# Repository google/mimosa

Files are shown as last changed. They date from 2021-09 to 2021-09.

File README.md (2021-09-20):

# MIMOSA

MIMOSA - **M**ultiple **I**nput **M**ultiple **O**utput **S**witches. The mission of the project is to capture user's intent via as many physiological triggers (press of button, blink of an eye, flick of a cheek, shake of a toe) as possible, and provide an easy interface to transduce the intent into digital actions.

At this time MIMOSA is focused on enabling students, makers, and DIY community to quickly prototype accessible and inclusive input devices. In the future the list of complete functional and tested devices (together with bills of materials and assembly+programming instructions) will be expanding. Please see the section "Reference Devices" below for some of the devices currently prototyped.

# System Features
1. **Sensitive and adaptive** - focus on the users abilities, that could be changing over time.
2. **Maker-friendly** - the system is comprised of components that are easy to get (via Sparkfun, Adafruit, Digikey), and easy to program (support for Arduino, CircuitPython).
3. **Extandable** - multi-modal sensing modules can be daisy chained together to enable multi-trigger applications (gaming, chorded typing, advanced device control, etc.)
4. **Low-cost**. The system is breathing accessibility not only with it's functions, but also with the price point.
5. **Well-documented reference designs** - mouse control, fast-typing and accessible keyboard, gaming, Android device control, ChromeOS device control.

While MIMOSA is not an officially Google supported project, it is a great start for engineers, makers, students, hobbyists into versatile and accessible input devices.

# Example Development and Deployment Process
1. Define sensing modalities and strategies for triggering. 
2. Put together a system with MIMOSA modules to provide means for sensing and user feedback. Two tips:
  a. Often it is a good idea to start with a block diagram and a high level design document.
  b. Iterate quickly. Engage with the users early.
3. Test the system with the user and adjust sensitivity settings, modules placement, mechanical arrangements, etc.

# Custom Modules - Design Blueprints Available Throught This Repository
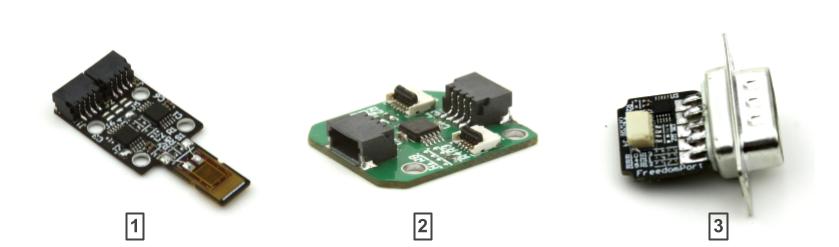
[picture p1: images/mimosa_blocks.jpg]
blocks

1. **High dynamic range force sensor**. This board can be used to monitor force application along 1 axis with an impressive sensitivity (well below 1g), and good dynamic range such that a stronger force can still be registered without saturation.
2. **Joystick interface**. The goal of the board is to provide a solderless interface board compatible with the tiny joysticks available on the market. Tested with [1](https://www.adafruit.com/product/3103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), [2](https://www.amazon.com/gp/product/B08397JQZG).
3. **D-sub 9-pin joystick interface** inspired by FreedomWing. Allows the connection of a widely used DB9 joysticks into the Stemma QT aka QWIIC infrastructure.

# Off-the-shelf Module Ideas
As MIMOSA is based on a widely adopted solderless communication and power distribution system (Adafruit Stemma QT, or Sparkfun QWIIC), there are many modules developed for all sort of applications that can be used together with MIMOSA modules. 

Examples of such modules:
- IMU modules, magnetometers, accelerometeres, gyroscopes.
- Proximity sensors
- Interface boards

# Reference Devices
Based on the modules developped there are a few reference implmentations of ready to go devices for end user applications. All devices are ready to go out of the box. All devices also come Arduino and/or CircuitPython compatible, so they are very easy to modify for different applications, different abilities, and expanded to comprise more sophisticated systems.

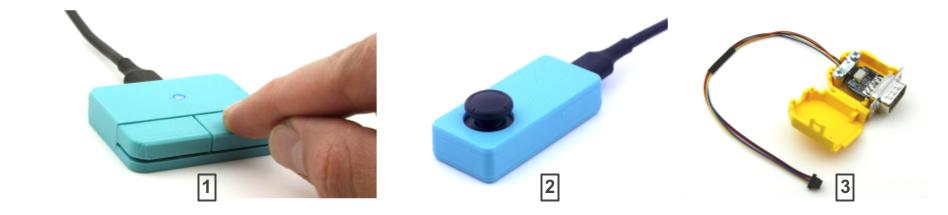
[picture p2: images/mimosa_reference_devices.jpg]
devices


Following devices are provided as a reference: 
1. Dual force buttons with USB-C interface that supports standards HID mouse/keyboard protocol.
2. Tiny joystick (tinyjoy). Just a standalone small joystick device with USB-C interface.
  a. HID joystick implementation.
  b. HID mouse implmentation.

More complex devices available through separate repositories:

4. Palmouse - magnetometer-based airmouse (inclination -> mouse speed) with an additional joystick, two MIMOSA force buttons, and USB interface.
5. Chorda - simiar form factor as Palmouse, this device is built for both hands, with two additional buttons on each hand. The key idea is that it cab be used as a mouse and as a chorded keyboard!

# Navigating the Repository
- The directories with names starting with "pcba_" are the source files of the custom modules described above (schematics + board layour + bom + fabrication files). They also include accompanying arduino libraries and examples where applicable. 
- The directories with the names starting with "device" contain the source files and code examples needed to put together complete devices. This usually includes a mechanical enclosure, photos, and documentation.

# Source Files
1. Schematic diagram + board layout (Altium).
2. Enclosure (STLs, STEP file exported from Autocad Fusion 360).
3. Firmware libraries and sketches compatible with Arduino IDE are included.

# License
This project is licensed under the Apache v2.0 License - see the [LICENSE.md](LICENSE.md) file for details

# Contributing
Thank you for your interest - please review CONTRIBUTING.md!

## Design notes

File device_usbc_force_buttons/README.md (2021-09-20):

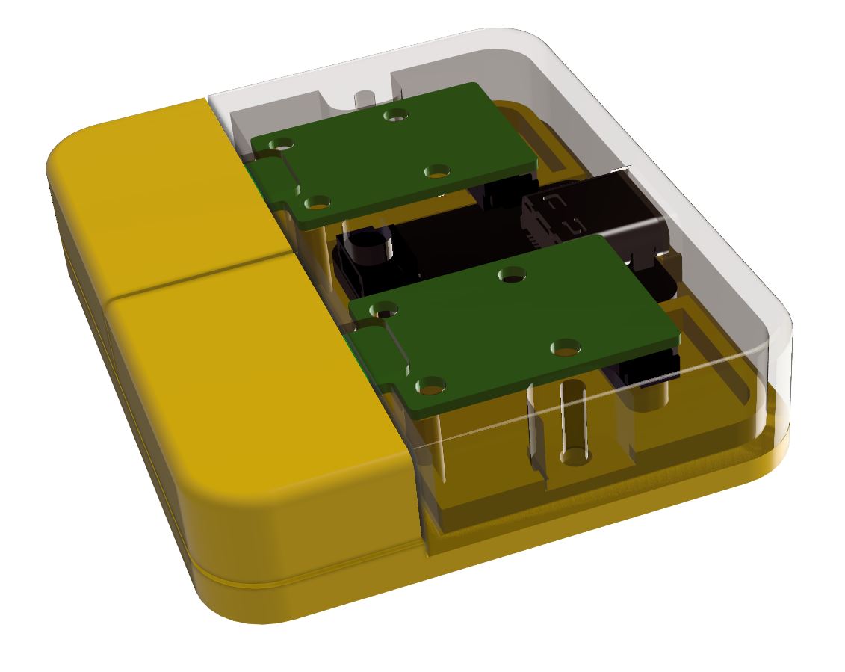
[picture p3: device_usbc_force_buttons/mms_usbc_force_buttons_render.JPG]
USB-C Force Buttons Render


# Getting Started

When the USB-C cord is plugged in the device should show up as an HID keyboard (assuming default setting). Try pressing the buttons and see if you can get the two letter from the two buttons to show up in the Notepad window.

When the sensitivity needs to be adjusted a few extra steps are needed to modify the parameters and reprogram the device, please follow the guidelines in the sections "Getting Started with Arduino Development" below.

# Getting Started with Arduino Development

1. Clone this repo into your local machine.

1. Get all the prerequisites from Adafruit
- QT Py SAMD21 Arduino IDE [board support](https://learn.adafruit.com/adafruit-qt-py/arduino-ide-setup)
- ADS1X15 Library

2. Install mimosa_force Arduino library by unzipping the library from force/arduino_lib/ into your Arduino library folder.

3. Open mimosa\device_usbc_force_buttons\firmware\mms_usbc_force_buttons\mms_usbc_force_buttons.ino and try to program the board with it.

If all the steps were completed, the device should reprogram.

# Adjusting the Sensitivity
Sensitivity is adjusted through an integer constant change. The constant that is at the top of the file named "SENSITIVITY" should do the trick. The parameter should be adjusted as following:
1 - super sensitivity
5 - least sensitive

# Streaming Raw Data Samples
Serial.println(button.rawSample()) should do the trick.

# Streaming Processed Data Samples
Serial.println(button.processedSample()) should do the trick.

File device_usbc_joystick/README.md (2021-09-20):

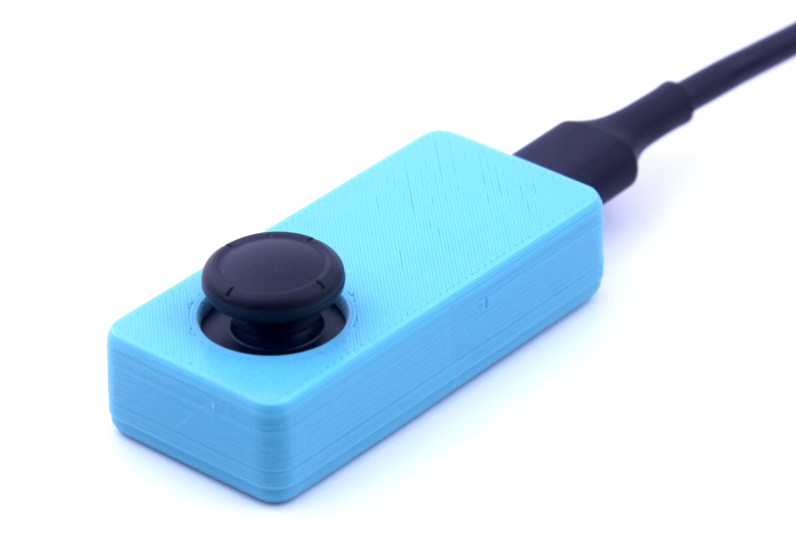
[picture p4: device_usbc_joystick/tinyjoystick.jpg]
USB-C Force Buttons Render


USB-C Joystick             |  Inside of USB-C Joystick
:-------------------------:|:-------------------------:
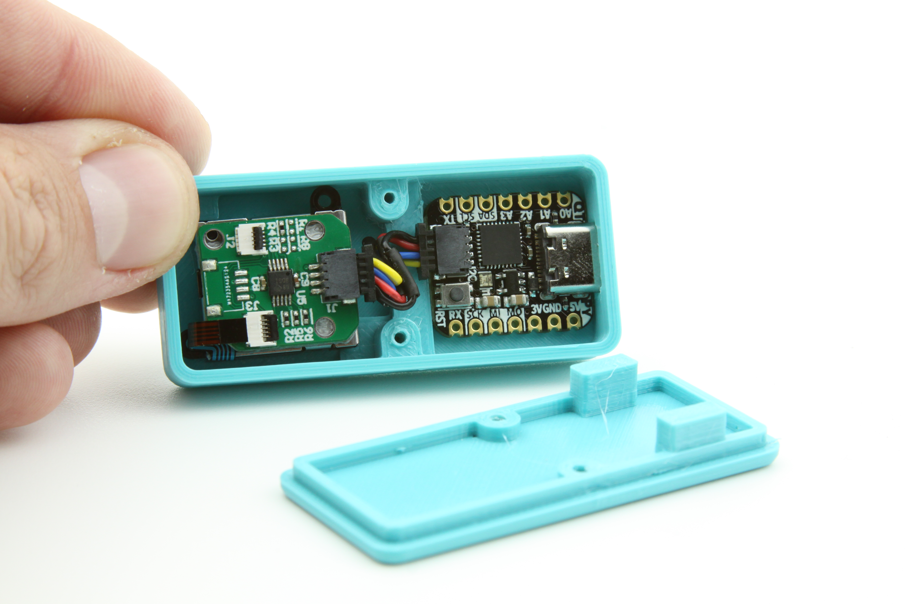
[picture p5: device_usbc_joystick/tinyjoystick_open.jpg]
      |  

# Getting Started

When the USB-C cord is plugged in the device should show up as an HID mouse. Pressing the joystick is equivalen to a mouse right click.

# Getting Started with Arduino Development

1. Clone this repo into your local machine.

1. Get all the prerequisites from Adafruit
- QT Py SAMD21 Arduino IDE [board support](https://learn.adafruit.com/adafruit-qt-py/arduino-ide-setup)
- ADS1X15 Library

3. Open mimosa\device_usbc_joystick\firmware\mms_usbc_joystick_mouse\mms_usbc_joystick_mouse.ino and try to program the board with it.

If all the steps were completed, the device should reprogram.

# Streaming Raw Data Samples from X and Y Channels
	int xReading = mouse_joystick.readADC_SingleEnded(0);
	int yReading = mouse_joystick.readADC_SingleEnded(1);
	Serial.print(xReading);
	Serial.print(", ");
	Serial.println(yReading);

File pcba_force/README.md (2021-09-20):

# MIMOSA Force

Getting Started with Arduino IDE with Adafruit QT Py as Controller
Needless to say, other controllers are also compatible with the MIMOSA Force sensor.
1. Follow [this guide](https://learn.adafruit.com/adafruit-qt-py/using-with-arduino-ide) to add QT Py support into Arduino IDE.
2. Install Mimosa_Force library into Arduino IDE following [this guide](https://www.arduino.cc/en/Guide/Libraries). (Also add external board database from [this guide](https://learn.adafruit.com/add-boards-arduino-v164/setup))
3. Start Arduino IDE. A good starting point is to blink LEDs with a force-triggered button. Check out an example from File -> Examples -> Mimosa_Force.

Default I2C address is 0x48. The device is compatible with both 3.3V and 5V operation and logic levels.

# License
This project is licensed under the Apache v2.0 License - see the [LICENSE.md](LICENSE.md) file for details

# Contributing
Thank you for your interest - please review CONTRIBUTING.md!

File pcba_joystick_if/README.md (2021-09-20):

# Joystick Interface (IF) board

This tiny low-cost board is designed to digitize tiny joysticks (see the exact models below) and be compatible with QWIIC/Stemma QT I2C communication convention.

## Compatibility
1. PSP3000 translational joystick with flex interface (e.g. from Adafruit).
2. Nintendo Switch replacement joysticks available from Amazon.

## Source Files
1. Schematic diagram + board layout (Altium).
3. No firmware images/examples or enlosure mechanical designs are included in this package, but take a look at the joystick_tiny project, where there us an example of how to use it together with a controller board as a USB joystick controlled mouse.

## License
This project is licensed under the Apache v2.0 License - see the [LICENSE.md](LICENSE.md) file for details

## Contributing
Thank you for your interest - please review CONTRIBUTING.md!

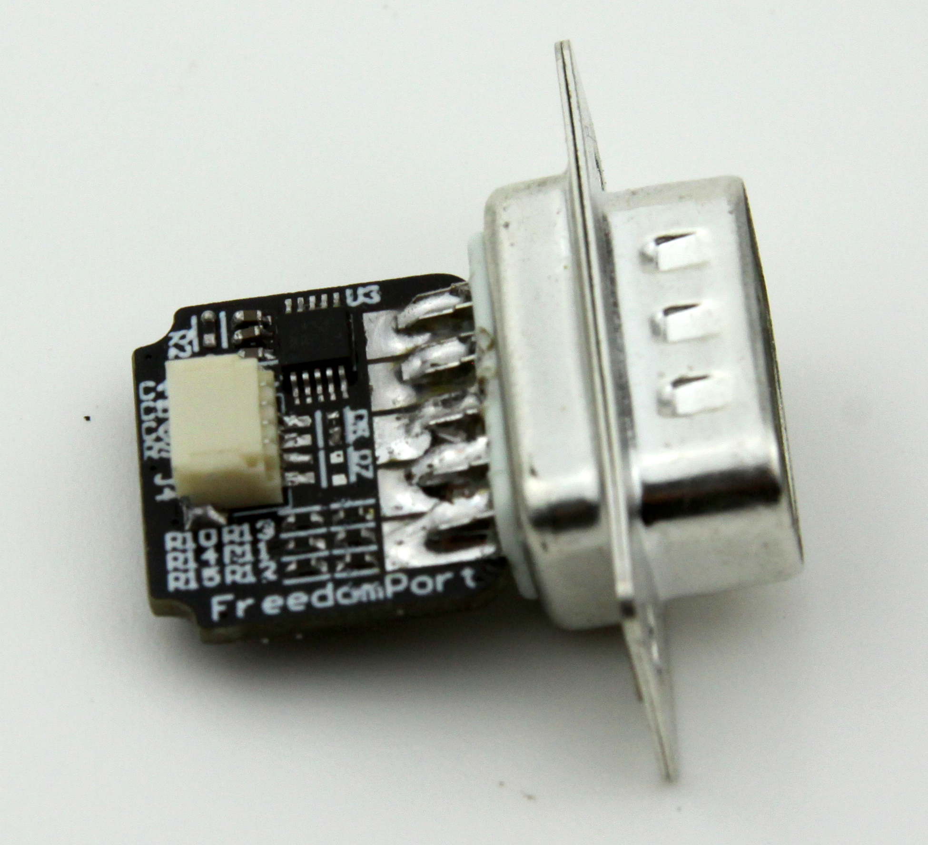
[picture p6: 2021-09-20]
pcba_freedomport/IMG_1879_refined.JPG

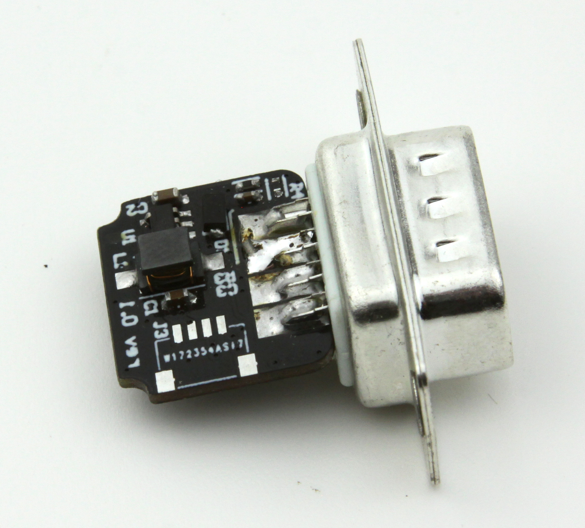
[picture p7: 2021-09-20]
pcba_freedomport/IMG_1884_refined.JPG

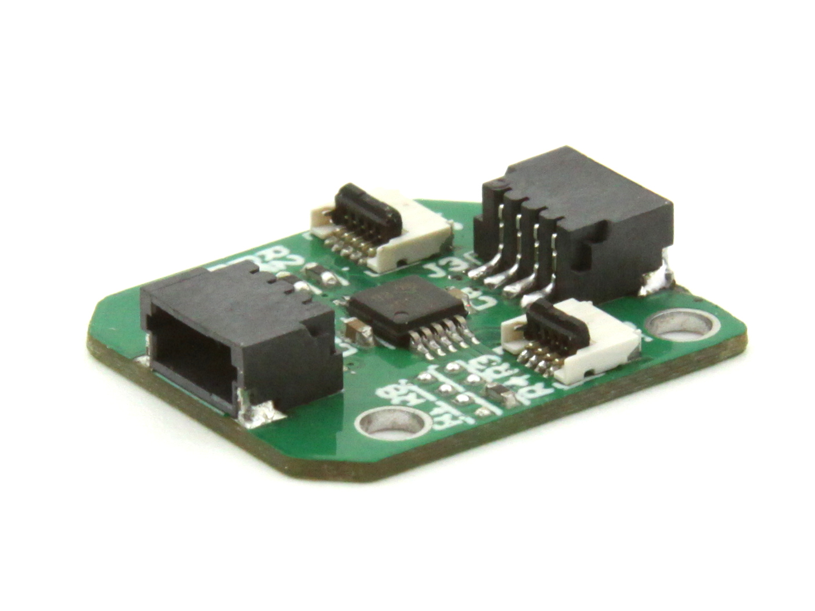
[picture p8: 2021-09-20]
pcba_joystick_if/joystick_if_bareboard.jpg

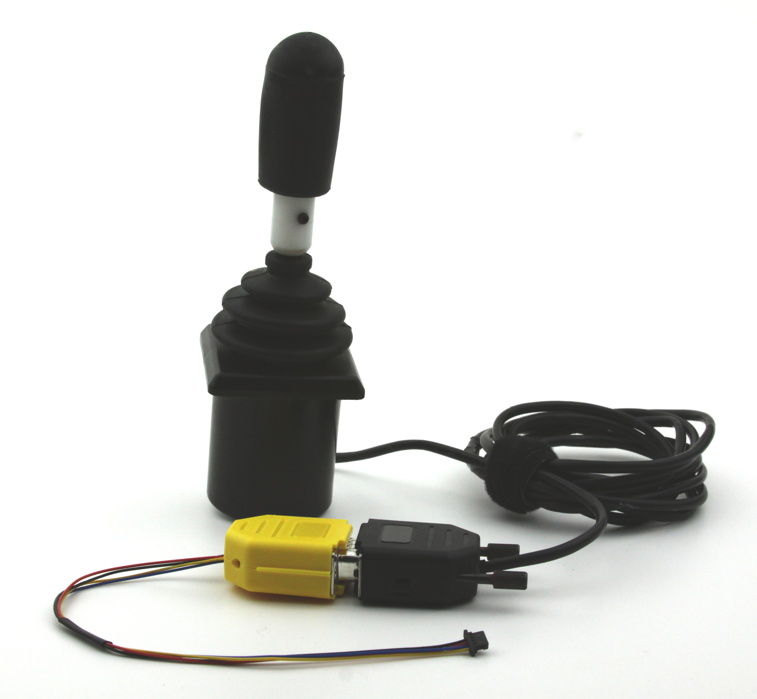
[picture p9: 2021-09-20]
pcba_freedomport/IMG_1874_refined.JPG

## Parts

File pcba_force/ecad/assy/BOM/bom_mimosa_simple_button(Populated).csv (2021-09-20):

Comment | Description | Designator | Footprint | LibRef | Quantity
1µF | CAP CER 1UF 10V X5R 0402, CAP CER 1UF 10V X7S 0402 | C1, C5, C? | SMD-0402C | GRM155R61A105KE15D, GCM155C71A105KE38D | 5
0.10µF | CAP CER 0.1UF 10V X5R 0402 | C6 | SMD-0402C | GRM152R61A104KE19D | 1
4208 |  | J1, J2, J3 | 4208 | 4208 | 3
0.0 | RES SMD 0.0OHM JUMPER 1/10W 0402 | R1, R3, R4, R8 | SMD-0402-RES | ERJ-2GE0R00X | 4
348 | RES SMD 348 OHM 1% 1/10W 0402 | R5, R7 | SMD-0402-RES | ERJ-2RKF3480X | 2
4.7k | RES SMD 4.7K OHM 5% 1/10W 0402 | R17, R18 | SMD-0402-RES | ERJ-2GEJ472X | 2
1k | RES SMD 1K OHM 1% 1/10W 0402 | R? | SMD-0402-RES | ERJ-2RKF1001X | 1
1M | RES SMD 1M OHM 1% 1/10W 0402 | R? | SMD-0402-RES | ERJ-2RKF1004X | 1
350 Ohm, Strain Gauge Sensor |  | S1, S2 | BF350-3AA-NARROW | BF350-3AA | 2
INA331DGK | Low-Power, Single Supply, CMOS, Instrumentation Amplifier 8-VSSOP -55 to 125 | U1 | SOP65P490X110-8N | INA331DGK | 1
ADS1015IDGST | 12-Bit, 3.3kSPS, 4-Ch Delta-Sigma ADC With PGA, Oscillator, VREF, Comparator and I2C Interface 10-VSSOP -40 to 125 | U2 | SOP50P490X110-10N | ADS1015IDGST | 1
TPS60402DBVT | 60mA Charge Pump Voltage Inverter with Fixed 50kHz Operation 5-SOT-23 -40 to 85 | U? | SOT95P280X145-5N | TPS60402DBVT | 1

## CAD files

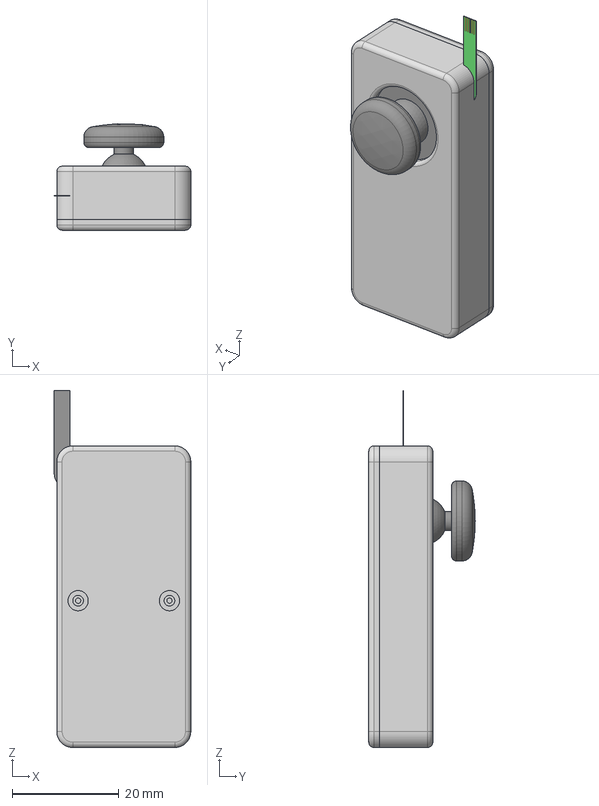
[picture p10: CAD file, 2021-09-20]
device_usbc_joystick/mcab/joystick_assy_switch.step
25.6 x 20.0 x 66.9 mm
Sheet
SM04B-SRSS-TB x 3
PCB
b3u-1000p

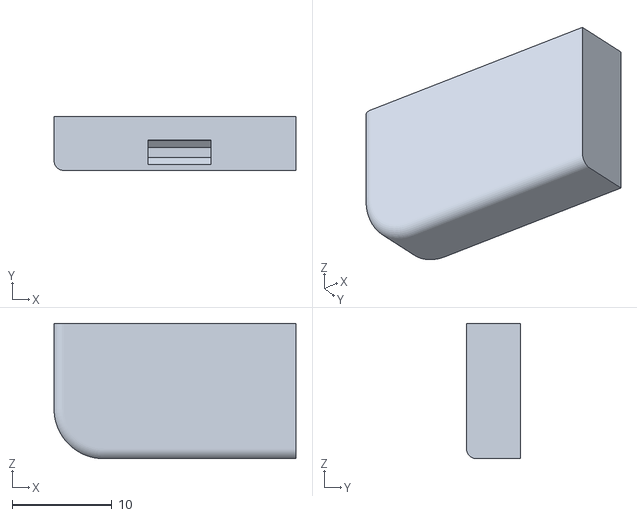
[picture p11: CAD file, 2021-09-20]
device_usbc_force_buttons/enclosure/mms_usbc_force_buttons_left.stl
24.3 x 5.42 x 13.6

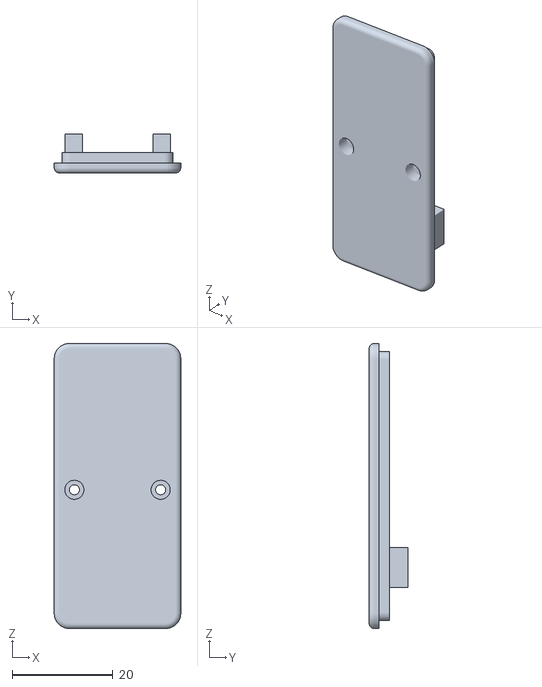
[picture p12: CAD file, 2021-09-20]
device_usbc_joystick/mcab/tinyjoystick_enclosure_bottom.stl
25.1 x 7.70 x 56.5

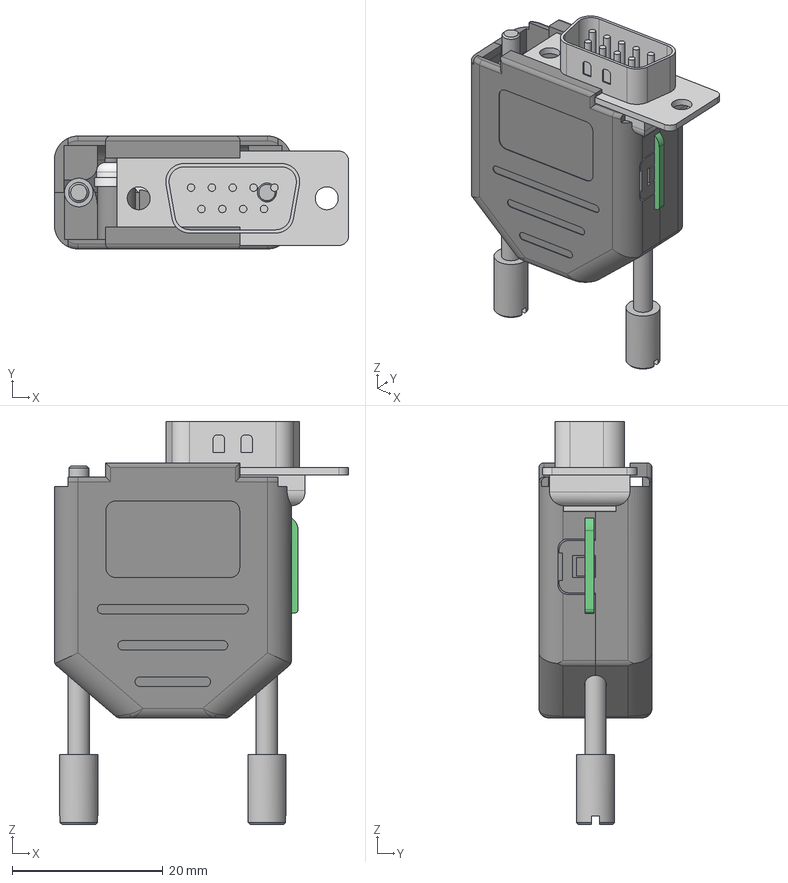
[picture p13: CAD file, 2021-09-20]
pcba_freedomport/mcad/freedomport.step
39.1 x 15.0 x 53.5 mm
SM04B-SRSS-TB x 2
connector_a-ds_09_ll_z
972-009-01SR011-B
jackscrew x 2
strain relief 972 small
strain relief metal 972 small
screw 972 x 2
972-009-01SR011-A

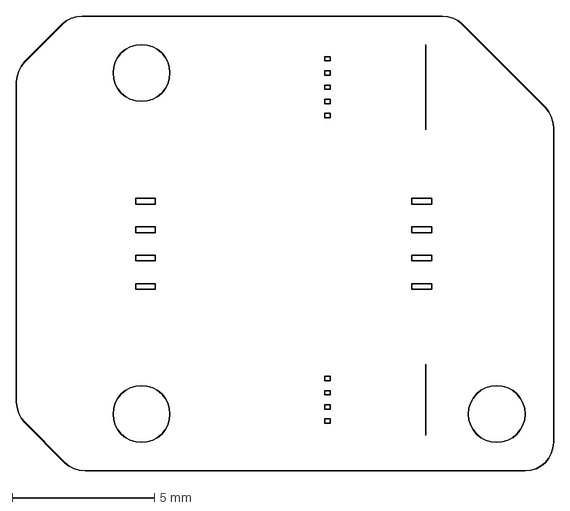
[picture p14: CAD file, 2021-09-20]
pcba_joystick_if/ecad/outline_v1.dxf
18.9 x 16.0 mm

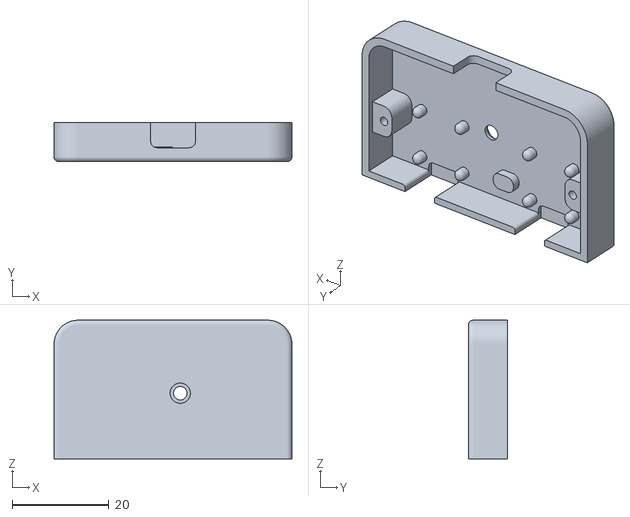
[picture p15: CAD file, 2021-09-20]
device_usbc_force_buttons/enclosure/mms_usbc_force_buttons_top.stl
49.2 x 8.12 x 28.7

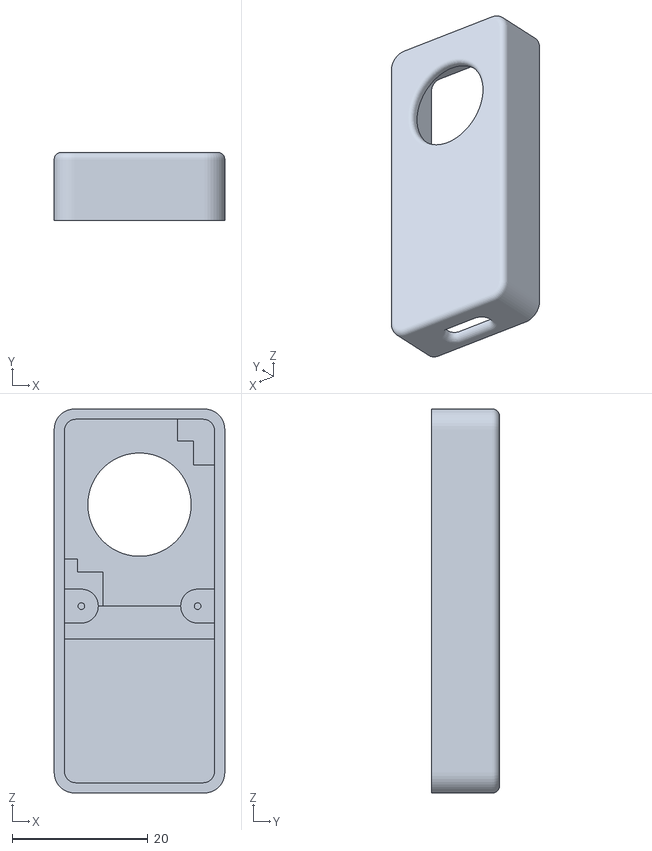
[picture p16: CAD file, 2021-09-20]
device_usbc_joystick/mcab/tinyjoystick_enclosure_top.stl
25.1 x 10.0 x 56.5

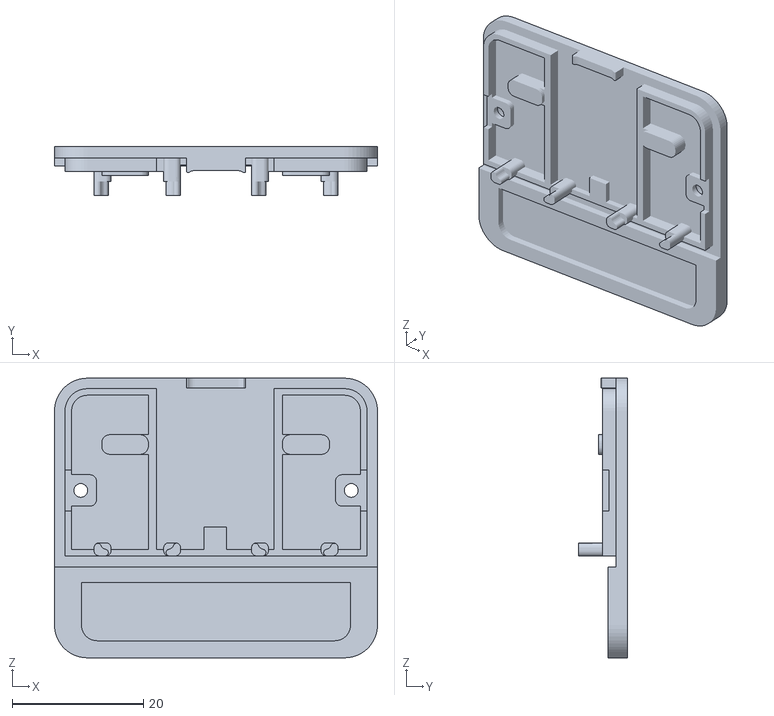
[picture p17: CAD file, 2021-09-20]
device_usbc_force_buttons/enclosure/mms_usbc_force_buttons_bottom.stl
49.2 x 7.50 x 42.6

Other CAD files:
device_usbc_force_buttons/enclosure/mms_usbc_force_buttons_right.stl

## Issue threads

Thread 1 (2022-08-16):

No link, can't find with google search either

xgpt, 2022-08-16:
```
More complex devices available through separate repositories:

    Palmouse - magnetometer-based airmouse (inclination -> mouse speed) with an additional joystick, two MIMOSA force buttons, and USB interface.
    Chorda - simiar form factor as Palmouse, this device is built for both hands, with two additional buttons on each hand. The key idea is that it cab be used as a mouse and as a chorded keyboard!
```
Please link these repos

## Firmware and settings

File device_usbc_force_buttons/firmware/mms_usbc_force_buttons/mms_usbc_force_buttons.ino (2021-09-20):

/* Copyright 2021 Google LLC
 *
 * Licensed under the Apache License, Version 2.0 (the "License");
 * you may not use this file except in compliance with the License.
 * You may obtain a copy of the License at
 *
 *     https://www.apache.org/licenses/LICENSE-2.0
 *
 * Unless required by applicable law or agreed to in writing, software
 * distributed under the License is distributed on an "AS IS" BASIS,
 * WITHOUT WARRANTIES OR CONDITIONS OF ANY KIND, either express or implied.
 * See the License for the specific language governing permissions and
 * limitations under the License.
 */

#include "Adafruit_NeoPixel.h"
#include "mimosa_force.h"
#include <Keyboard.h>

// Adjust this parameter from 1 to 5 to
// adjust the sensitivity from super sensitive (1) to least sensitive (5)
#define SENSITIVITY 1

constexpr int16_t kThresholds[5] = {100, 1000, 5000, 10000, 20000};
constexpr int16_t kThresholdPress = kThresholds[SENSITIVITY - 1];
constexpr int16_t kThresholdRelease = - kThresholds[SENSITIVITY - 1]/4;
constexpr int kSamplingPeriodMilliseconds = 50;
constexpr float kSamplingPeriod = 0.001f * kSamplingPeriodMilliseconds;
constexpr int8_t kPolarity = -1;

Adafruit_NeoPixel pixels(1, PIN_NEOPIXEL);
MimosaForce button_right(kThresholdPress, kThresholdRelease, kSamplingPeriod, kPolarity);
MimosaForce button_left(kThresholdPress, kThresholdRelease, kSamplingPeriod, kPolarity);

// Use this option for OSX:
// char ctrlKey = KEY_LEFT_GUI;
// Use this option for Windows and Linux:
// const char leftKey = KEY_LEFT_CTRL;
// const char rightKey = KEY_LEFT_SHIFT;
const char leftKey = 'a';
const char rightKey = 'b';

void setup() {
  Serial.begin(57600);
  pixels.begin();
  Keyboard.begin();
  button_right.init(0x48);
  button_left.init(0x49);
}

void loop() {
  
  bool trigr = button_right.update();
  bool trigl = button_left.update();

  Serial.println(button_right.rawSample());
  
  if (trigr || trigl) {
    // First let's hangle the LED indicator.
    if (button_right.pressed() && !button_left.pressed()) {
      // Set pixel to amber color on press.
      pixels.setPixelColor(0, pixels.Color(0, 0, 255));
    } else if (!button_right.pressed() && button_left.pressed()){
      pixels.setPixelColor(0, pixels.Color(0, 255, 0));
    } else if (button_right.pressed() && button_left.pressed()){
      pixels.setPixelColor(0, pixels.Color(0, 255, 255));
    } else {
      // Turn off the pixel on release.
      pixels.clear();
    }
    pixels.show();

    // Now let's handle keycode press/release commands
    if (trigr && button_right.pressed()){
      Keyboard.press(rightKey);
    } else if (trigr && !button_right.pressed()){
      Keyboard.release(rightKey);
    }

    if (trigl && button_left.pressed()){
      Keyboard.press(leftKey);
    } else if (trigl && !button_left.pressed()){
      Keyboard.release(leftKey);
    }
  }
  delay(kSamplingPeriodMilliseconds);
}

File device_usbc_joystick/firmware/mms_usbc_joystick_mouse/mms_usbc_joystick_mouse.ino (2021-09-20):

/* Copyright 2021 Google LLC
 *
 * Licensed under the Apache License, Version 2.0 (the "License");
 * you may not use this file except in compliance with the License.
 * You may obtain a copy of the License at
 *
 *     https://www.apache.org/licenses/LICENSE-2.0
 *
 * Unless required by applicable law or agreed to in writing, software
 * distributed under the License is distributed on an "AS IS" BASIS,
 * WITHOUT WARRANTIES OR CONDITIONS OF ANY KIND, either express or implied.
 * See the License for the specific language governing permissions and
 * limitations under the License.
 */

#include "Mouse.h"
#include <Adafruit_ADS1X15.h>

// parameters for reading the joystick:
int range = 12;               // output range of X or Y movement
int responseDelay = 5;        // response delay of the mouse, in ms
int threshold = range / 4;    // resting threshold
int center = range / 2;       // resting position value
constexpr int kSamplingPeriodMilliseconds = 50;

bool mouseIsActive = false;    // whether or not to control the mouse
int lastSwitchState = LOW;        // previous switch state

Adafruit_ADS1115 mouse_joystick; //on mux ch0

void setup() {
  mouse_joystick.setGain(GAIN_ONE);
  mouse_joystick.setDataRate(RATE_ADS1115_250SPS);
  mouse_joystick.begin(0x4A);
  // take control of the mouse:
  Mouse.begin();
}

void loop() {
  // read the switch:
  int switchState = mouse_joystick.readADC_SingleEnded(2);
  if (switchState > 13000){
    switchState = LOW;
  }
  else {
    switchState = HIGH;
  }
  
  // if it's changed and it's high, toggle the mouse state:
  if (switchState != lastSwitchState) {
    if (switchState == HIGH) {
      mouseIsActive = !mouseIsActive;
    }
  }
  // save switch state for next comparison:
  lastSwitchState = switchState;
  
  // read and scale the two axes:
  int xReading = mouse_joystick.readADC_SingleEnded(0);
  int yReading = mouse_joystick.readADC_SingleEnded(1);

  if (xReading < 13000 && xReading > 12000){
     xReading = 0;
  } else {
     xReading = (int)-map(xReading, 4000, 23000, -20, 20);
  }  
  
  if (yReading < 13000 && yReading > 12000){
     yReading = 0;
  } else {
     yReading = (int)-map(yReading, 4000, 23000, -20, 20);
  }
 
  // if the mouse control state is active, move the mouse:
  if (mouseIsActive) {
    Mouse.move(xReading, yReading, 0);
  }
  
  delay(responseDelay);
}

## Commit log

2020-09-22 Initial commit with the hardware design for the MIMOSA host.
    [Bill of Materials-mimosa_host_fsr_sch(Populated).csv, Pick Place for mimosa_host_fsr(Populated).csv, enclosure_body.stl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]
2021-09-20 Major release: new force sensor based on strain gauge tech, joystick interface boards are added, arduino libraries and examples are added.
    [Bill of Materials-mimosa_host_fsr_sch(Populated).csv, Pick Place for mimosa_host_fsr(Populated).csv, bom_mimosa_simple_button(Populated).csv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]
